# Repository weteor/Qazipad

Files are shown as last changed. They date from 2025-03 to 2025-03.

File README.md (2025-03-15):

### Qazipad

unistagger qaz-like w/ numpad

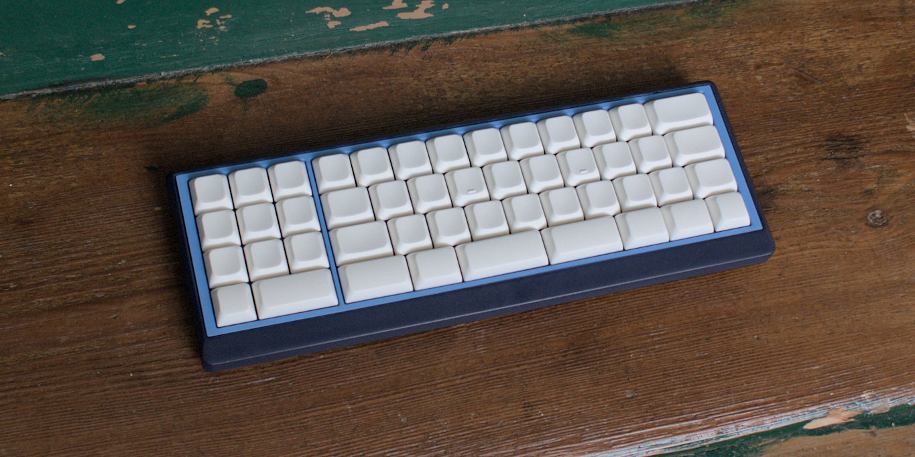
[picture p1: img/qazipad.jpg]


## Features

- MX-Hotswap sockets
- CH552T Controller (w/ FAK firmware), uses japanese duplex matrix
- reversable pcb so you may have numpad right or left
- gerber and case files are supplied (kicad files, stl as well as cadquery files)
- completely open source, permissive license ([CERN-OHL-P](https://cern-ohl.web.cern.ch/home))
- only V2: removeable numpad, more numpad options
  - **V2 pcb is not fully tested yet**

##### layout options

current version in repo (V2):

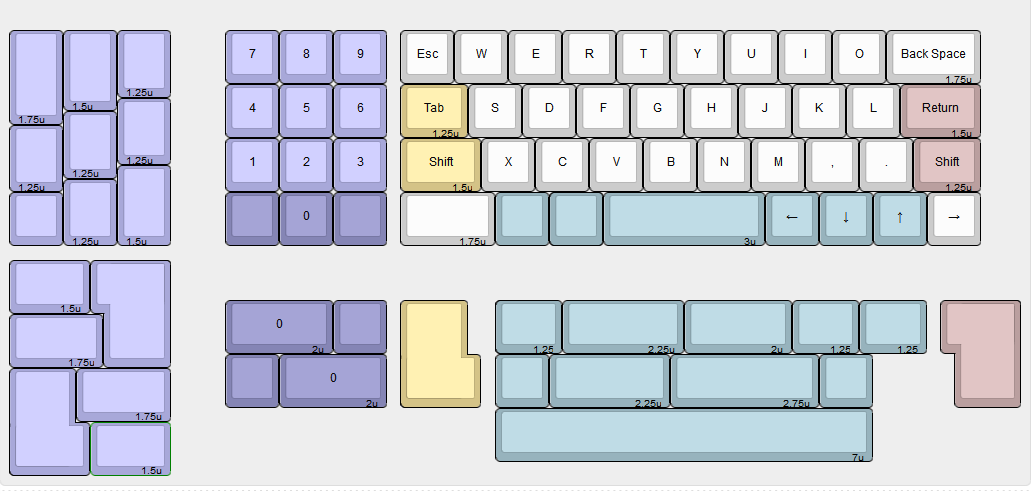
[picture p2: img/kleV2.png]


V1:

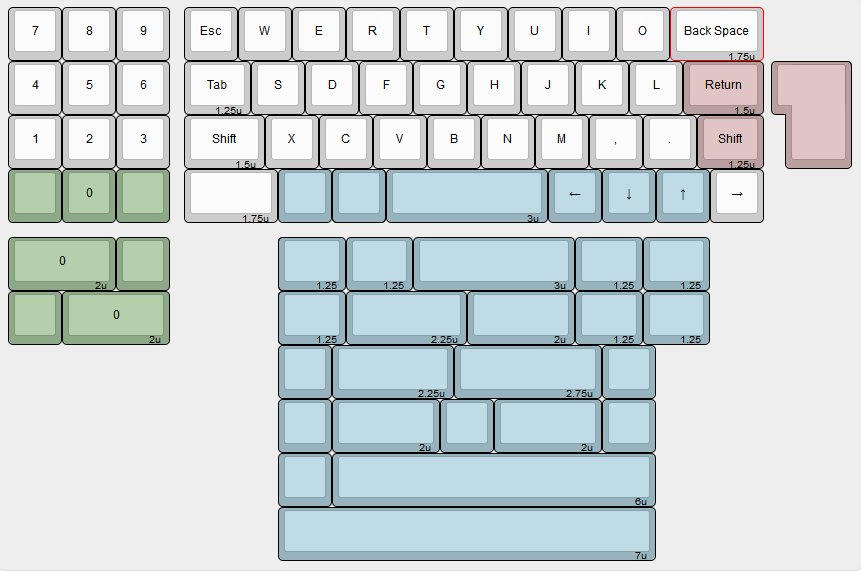
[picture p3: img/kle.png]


not all stab option are tested with the plate. They should work, but maybe there are cases which require some work on the plate.

## Want one?

All production files you need to build your own board can be found [here](./prod/).

Apart from the pcb and optionally a case you need:

- 50 hotswap sockets

- 58 diodes (1N4148 int SOT-123)

- 50 of your favourite switches

- 1x CH552T (TSSOP-20)

- 1x USBLC6-2SC6 (SOT-23-6)

- 1x 10kOhm resistor (SMD 0603)

- 2x 5.1kOhm resistors (SMD 0603)

- 2x 100nF capacitors (SMD 0603)

- 1x USB Connector C-Type, 12 pin/16pin

- 8 M2 heat inserts

- 8 M2 srews (8mm)

### firmware

Config for FAK can be found [here](https://github.com/weteor/fak-config/tree/main/keyboards/qazipad)). Please also see [FAK-Firmware site](https://github.com/semickolon/fak) for more information

Bootloader should be available on plugin until firmware is written. After that either use the firmware BOOT to go into bootloader, or hold the boot button on the pcb pressed while pluggin in the usb cable.

### the rest

Everything in this repository is free to use however you might see fit. If you want to support me and my projects, please consider linking back to this repository if you build/change/use anything.

If you would like to send me a tip, you could do it [here](https://ko-fi.com/weteor) (Please don't feel like you have to).

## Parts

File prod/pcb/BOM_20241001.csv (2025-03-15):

Designator | Footprint | Quantity | Value | LCSC Part #
C1, C2, C3, C4 | C_0603_HandSolder | 4 | 100nF | C14663
D1, D10, D11, D12, D13, D14, D15, D16, D17, D18, D19, D2, D20, D21, D22, D23, D24, D25, D26, D27, D28, D29, D3, D30, D31, D32, D33, D34, D35, D36, D37, D38, D39, D4, D40, D41, D42, D43, D44, D45, D46, D47, D48, D49, D5, D50, D51, D52, D53, D54, D55, D56, D57, D58, D6, D7, D8, D9 | D_SOD-123 | 58 | D_Small | C81598
R1, R2, R4, R5 | R_0603_HandSolder | 4 | 5.1k | C23186
R3, R6 | R_0603_HandSolder | 2 | 10k | C25804
U1, U3 | SOT-23-6 | 2 | USBLC6-2SC6 | C2687116
U2, U4 | TSSOP-20_4.4x6.5mm_P0.65mm | 2 | ~ | C111367

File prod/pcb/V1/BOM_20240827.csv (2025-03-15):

Designator | Footprint | Quantity | Value | LCSC Part #
C1, C2 | C_0603_HandSolder | 2 | 100nF | C14663
D1, D10, D11, D12, D13, D14, D15, D16, D17, D18, D19, D2, D20, D21, D22, D23, D24, D25, D26, D27, D28, D29, D3, D30, D31, D32, D33, D34, D35, D36, D37, D38, D39, D4, D40, D41, D42, D43, D44, D45, D46, D47, D48, D49, D5, D50, D51, D52, D53, D54, D55, D56, D57, D58, D6, D7, D8, D9 | D_SOD-123 | 58 | D_Small | C81598
R1, R2 | R_0603_HandSolder | 2 | 5.1k | C23186
R3 | R_0603_HandSolder | 1 | 10k | C25804
SW42 | SW_SPST_TL3342 | 1 | BOOT | C115357
U1 | SOT-23-6 | 1 | USBLC6-2SC6 | C2687116
U2 | TSSOP-20_4.4x6.5mm_P0.65mm | 1 | ~ | C111367

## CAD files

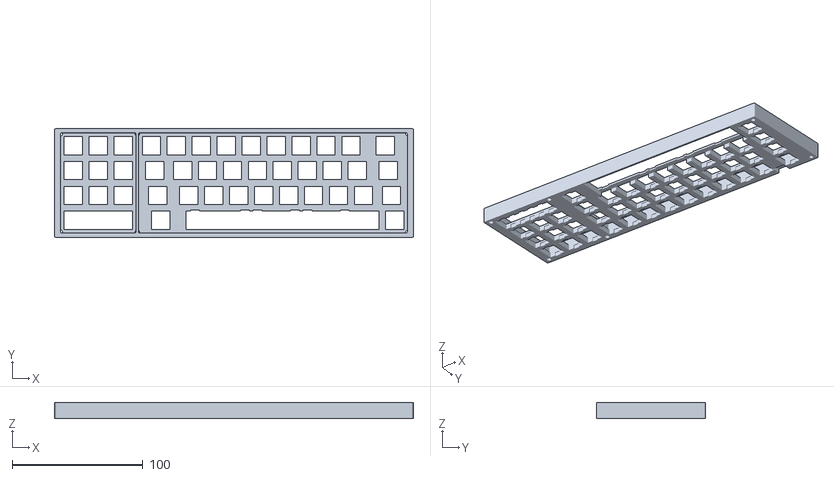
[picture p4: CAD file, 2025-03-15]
prod/case/insert.stl
274.2 x 83.0 x 12.5

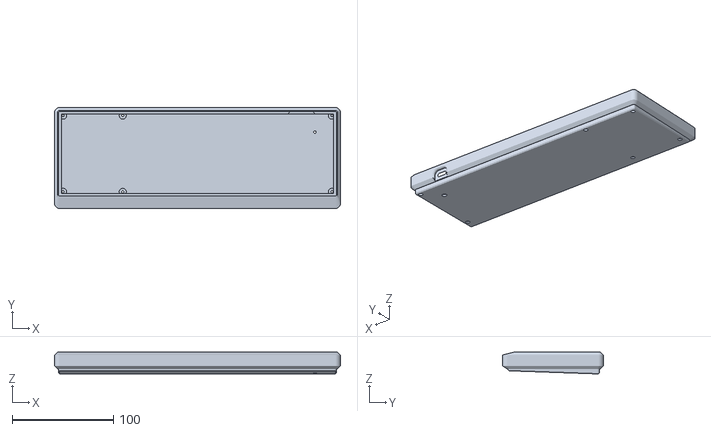
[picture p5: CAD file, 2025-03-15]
prod/case/bottom.stl
282.4 x 99.7 x 21.7

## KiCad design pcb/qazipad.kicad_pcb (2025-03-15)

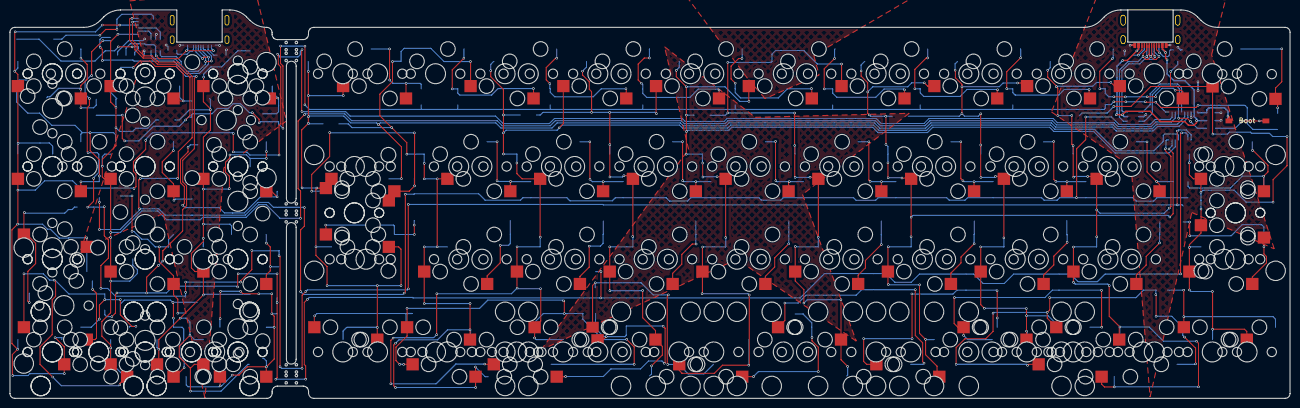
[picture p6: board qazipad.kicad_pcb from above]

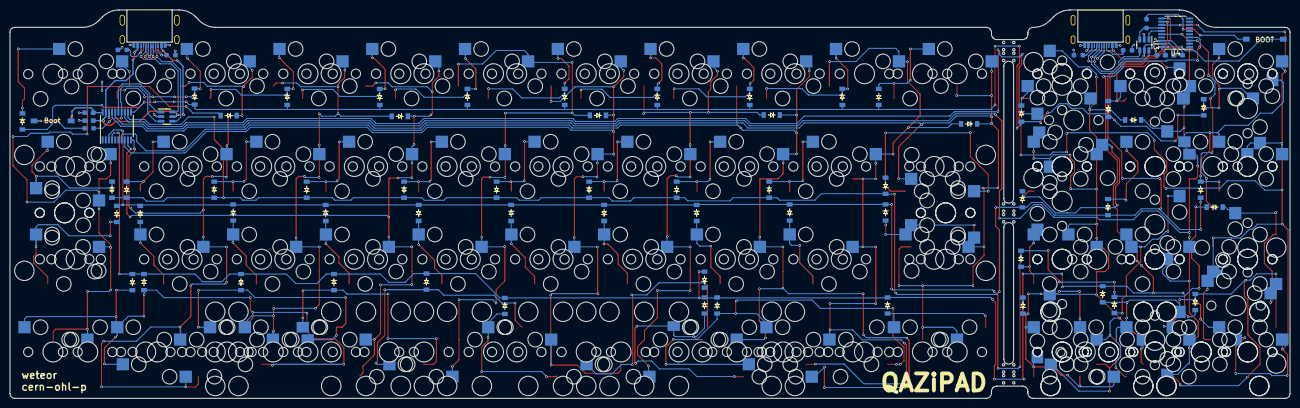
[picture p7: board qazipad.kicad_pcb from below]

Board: 2 copper layers, 262.9 x 79.8 mm, 232 parts (148 on the bottom side), 89 nets.

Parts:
C1, C2, C3, C4: 100nF; C_0603_HandSolder
D1, D2, D3, D4, D5, D6, D7, D8, D9, D10, D11, D12, D13, D14, D15, D16, D17, D18, D19, D20, D21, D22, D23, D24, D25, D26, D27, D28, D29, D30, D31, D32, D33, D34, D35, D36, D37, D38, D39, D40, D41, D42, D43, D44, D45, D46, D47, D48, D49, D50, D51, D52, D53, D54, D55, D56, D57, D58: D_Small; D_SOD-123
H1, H2, H3, H4, H5, H6: MouseBites; mousebites_2mm
J1, J2, J3: USB_C_Receptacle_USB2.0; USB-C-12-Pin-MidMount
R1, R2, R4, R5: 5.1k; R_0603_HandSolder
R3, R6: 10k; R_0603_HandSolder
S1, S2, S12, S13, S14, S21: 2u; STAB_MX_P_2u
S3, S4, S8, S10: ISO-Enter; STAB_MX_ISO
S5, S18: 7u; STAB_MX_P_7u
S6, S19: 3u; STAB_MX_P_3u
S7, S16: 2.25u; STAB_MX_P_2.25u
SW1, SW2, SW3, SW6, SW7, SW8, SW10, SW11, SW12, SW15, SW16, SW17, SW18, SW19, SW20, SW21, SW23, SW24, SW25, SW27, SW28, SW29, SW30, SW31, SW32, SW33, SW34, SW35, SW36, SW37, SW38, SW39, SW40, SW43, SW44, SW45, SW47, SW48, SW49, SW51, SW52, SW53, SW55, SW56, SW57, SW58, SW59, SW61, SW63, SW67, SW68, SW71, SW72, SW73, SW75, SW76, SW77, SW80, SW81, SW82, SW83, SW84, SW85, SW86, SW89, SW90, SW91, SW94, SW95, SW96, SW97, SW99, SW100, SW101, SW102, SW103, SW104, SW105, SW106, SW107, SW110, SW111, SW112, SW113, SW115, SW116, SW117, SW119, SW120, SW121, SW122, SW125, SW126, SW127, SW128, SW129, SW131, SW138, SW140: SW_Push; CherryMX_Hotswap_3d_Socketfront
SW4, SW5, SW9, SW13, SW14, SW22, SW26, SW41, SW46, SW50, SW54, SW62, SW66, SW69, SW70, SW74, SW78, SW79, SW87, SW92, SW98, SW109, SW114, SW118, SW123, SW132, SW141: SW_Push; CherryMX_Hotswap_3d
SW42, SW108: BOOT; Micro_Push_Button_3x6x2.5mm
SW60, SW64, SW65, SW88, SW93, SW124: SW_Push; CherryMX_Hotswap_1.25u
SWi: BOOT; Micro_Push_Button_3x6x2.5mm
U1, U3: USBLC6-2SC6; SOT-23-6
U2, U4: TSSOP-20_4.4x6.5mm_P0.65mm

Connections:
+3.3V: C1.1, SW42.2, SW108.2, U2.20 (V33)
+3.3VA: C3.1, SWi.2, U4.20 (V33)
+5VA: C4.1, J2.A4 (VBUS), J2.A9 (VBUS), J2.B4 (VBUS), J2.B9 (VBUS), U3.5 (VBUS), U4.19 (VCC)
BOOT: R3.2, SW42.1, SW108.1
BOOT_NUM: R6.2, SWi.1
CC1: J1.A5 (CC1), J3.B5 (CC2), R1.1
CC1_NUM: J2.A5 (CC1), R4.1
CC2: J1.B5 (CC2), J3.A5 (CC1), R2.1
CC2_NUM: J2.B5 (CC2), R5.1
D1: D1.2 (A), SW1.2, SW39.2, SW61.2
D2: D2.2 (A), SW2.2, SW63.2, SW67.2, SW99.2
D3: D3.2 (A), SW3.2, SW68.2, SW97.1, SW132.1
D4: D4.2 (A), SW19.1, SW20.1, SW21.1, SW22.1, SW60.2, SW84.1, SW85.1, SW86.1, SW87.1, SW88.2
D5: D5.2 (A), SW4.2, SW5.2, SW69.2, SW70.2
D6: D6.2 (A), SW6.1, SW71.2, SW104.2
D7: D7.2 (A), SW7.2, SW72.2
D8: D8.2 (A), SW8.2, SW73.2, SW110.2, SW140.1
D9: D9.2 (A), SW9.2, SW74.2, SW114.2
D10: D10.1 (K), SW10.1, SW75.2, SW119.2
D11: D11.1 (K), SW11.1, SW76.2, SW138.2
D12: D12.1 (K), SW12.2, SW77.2, SW129.2
D13: D13.2 (A), SW27.1, SW28.1, SW29.1, SW41.1, SW62.2, SW94.1, SW95.1, SW96.1
D14: D14.1 (K), SW13.2, SW14.2, SW78.2, SW79.2, SW131.2, SW141.2
D15: D15.2 (A), SW15.2, SW80.2
D16: D16.2 (A), SW16.2, SW31.1, SW81.2
D17: D17.2 (A), SW17.2, SW30.1, SW82.2
D18: D18.2 (A), SW18.2, SW83.2
D19: D19.1 (K), SW19.2, SW84.2
D20: D20.1 (K), SW20.2, SW85.2
D21: D21.1 (K), SW21.2, SW86.2
D22: D22.1 (K), SW22.2, SW60.1, SW87.2, SW88.1
D23: D23.2 (A), SW23.2, SW89.2
D24: D24.2 (A), SW24.2, SW90.2
D25: D25.2 (A), SW25.2, SW91.2
D26: D26.2 (A), SW26.2, SW92.2, SW93.1
D27: D27.1 (K), SW27.2, SW94.2
D28: D28.1 (K), SW28.2, SW95.2
D29: D29.1 (K), SW29.2, SW96.2
D30: D30.2 (A), SW36.1, SW37.1, SW38.1, SW66.2, SW103.1, SW105.1, SW106.1, SW107.1
D31: D31.1 (K), SW41.2, SW62.1
D32: D32.2 (A), SW32.2, SW100.2
D33: D33.2 (A), SW33.2, SW101.2
D34: D34.2 (A), SW34.2, SW102.2
D35: D35.2 (A), SW35.2, SW98.2
D36: D36.1 (K), SW36.2, SW105.2
D37: D37.1 (K), SW37.2, SW106.2
D38: D38.1 (K), SW38.2, SW107.2
D39: D39.2 (A), SW47.1, SW48.1, SW49.1, SW50.1, SW64.2, SW115.1, SW116.1, SW117.1, SW118.1
D40: D40.2 (A), SW40.1, SW55.1, SW56.1, SW57.1, SW58.1, SW59.1, SW125.1, SW126.1, SW127.1, SW128.1
D41: D41.1 (K), SW66.1, SW103.2
D42: D42.2 (A), SW43.2, SW111.2
D43: D43.2 (A), SW44.2, SW112.2
D44: D44.2 (A), SW45.2, SW113.2
D45: D45.2 (A), SW46.2, SW109.1
D46: D46.1 (K), SW47.2, SW115.2
D47: D47.1 (K), SW48.2, SW116.2
D48: D48.1 (K), SW49.2, SW117.2
D49: D49.1 (K), SW50.2, SW64.1, SW118.2
D50: D50.2 (A), SW51.2, SW120.2
D51: D51.2 (A), SW52.2, SW121.2
D52: D52.2 (A), SW53.2, SW122.2
D53: D53.2 (A), SW54.2, SW65.1, SW123.2, SW124.1
D54: D54.1 (K), SW55.2, SW125.2
D55: D55.1 (K), SW56.2, SW59.2, SW126.2
D56: D56.1 (K), SW40.2, SW57.2, SW127.2
D57: D57.1 (K), SW58.2, SW128.2
D58: D58.2 (A), SW10.2, SW11.2, SW12.1, SW13.1, SW14.1, SW75.1, SW76.1, SW77.1, SW78.1, SW79.1, SW119.1, SW129.1, SW131.1, SW138.1, SW140.2, SW141.1
GND: C1.2, C2.2, J1.A1 (GND), J1.A12 (GND), J1.B1 (GND), J1.B12 (GND), J3.A1 (GND), J3.A12 (GND), J3.B1 (GND), J3.B12 (GND), R1.2, R2.2, U1.2 (GND), U2.18 (GND)
GND1: C3.2, C4.2, J2.A1 (GND), J2.A12 (GND), J2.B1 (GND), J2.B12 (GND), R4.2, R5.2, U3.2 (GND), U4.18 (GND)
PORT+: J1.A6 (D+), J1.B6 (D+), J3.A6 (D+), J3.B6 (D+), U1.4 (I/O2)
PORT+_NUM: J2.A6 (D+), J2.B6 (D+), U3.4 (I/O2)
PORT-: J1.A7 (D-), J1.B7 (D-), J3.A7 (D-), J3.B7 (D-), U1.6 (I/O1)
PORT-_NUM: J2.A7 (D-), J2.B7 (D-), U3.6 (I/O1)
UDM: U1.1 (I/O1), U2.15 (P3.7)
UDM_NUM: U3.1 (I/O1), U4.15 (P3.7)
UDP: R3.1, U1.3 (I/O2), U2.14 (P3.6)
UDP_NUM: R6.1, U3.3 (I/O2), U4.14 (P3.6)
VBUS: C2.1, J1.A4 (VBUS), J1.A9 (VBUS), J1.B4 (VBUS), J1.B9 (VBUS), J3.A4 (VBUS), J3.A9 (VBUS), J3.B4 (VBUS), J3.B9 (VBUS), U1.5 (VBUS), U2.19 (VCC)
c1: SW1.1, SW2.1, SW3.1, SW4.1, SW5.1, SW39.1, SW63.1, SW67.1, SW68.1, SW69.1, SW70.1, SW97.2, SW99.1, SW132.2, U2.13 (P3.5), U4.13 (P3.5)
c2: D58.1 (K), SW6.2, SW7.1, SW8.1, SW9.1, SW61.1, SW71.1, SW72.1, SW73.1, SW74.1, SW104.1, SW110.1, SW114.1, U2.16 (P1.3), U4.16 (P1.3)
c3: D4.1 (K), SW15.1, SW16.1, SW17.1, SW18.1, SW30.2, SW31.2, SW80.1, SW81.1, SW82.1, SW83.1, U2.17 (P1.2)
c4: D13.1 (K), SW23.1, SW24.1, SW25.1, SW26.1, SW89.1, SW90.1, SW91.1, SW92.1, SW93.2, U2.7 (P1.0)
c5: D30.1 (K), SW32.1, SW33.1, SW34.1, SW35.1, SW98.1, SW100.1, SW101.1, SW102.1, U2.8 (P1.1)
c6: D39.1 (K), SW43.1, SW44.1, SW45.1, SW46.1, SW109.2, SW111.1, SW112.1, SW113.1, U2.9 (P3.1)
c7: D40.1 (K), SW51.1, SW52.1, SW53.1, SW54.1, SW65.2, SW120.1, SW121.1, SW122.1, SW123.1, SW124.2, U2.10 (P3.0)
r1: D1.1 (K), D6.1 (K), D10.2 (A), D15.1 (K), D19.2 (A), D23.1 (K), D27.2 (A), D32.1 (K), D36.2 (A), D42.1 (K), D46.2 (A), D50.1 (K), D54.2 (A), U2.11 (P3.3), U4.11 (P3.3)
r2: D2.1 (K), D7.1 (K), D11.2 (A), D16.1 (K), D20.2 (A), D24.1 (K), D28.2 (A), D33.1 (K), D37.2 (A), D43.1 (K), D47.2 (A), D51.1 (K), D55.2 (A), U2.12 (P3.4), U4.12 (P3.4)
r3: D3.1 (K), D8.1 (K), D12.2 (A), D17.1 (K), D21.2 (A), D25.1 (K), D29.2 (A), D34.1 (K), D38.2 (A), D44.1 (K), D48.2 (A), D52.1 (K), D56.2 (A), U2.3 (P1.5), U4.3 (P1.5)
r4: D5.1 (K), D9.1 (K), D14.2 (A), D18.1 (K), D22.2 (A), D26.1 (K), D31.2 (A), D35.1 (K), D41.2 (A), D45.1 (K), D49.2 (A), D53.1 (K), D57.2 (A), U2.4 (P1.6), U4.4 (P1.6)

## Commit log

2025-03-15 add pcb
    [qazipad.kicad_pcb, qazipad.kicad_sch]
2025-03-15 add case
2025-03-15 add prod files
    [BOM_20240827.csv, BOM_20241001.csv, POSITIONS_20241001.csv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]
